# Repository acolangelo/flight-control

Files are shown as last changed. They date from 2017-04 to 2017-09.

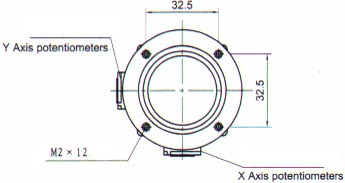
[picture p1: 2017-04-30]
3D/specs/3-axis-joystick-w-button-1.jpg

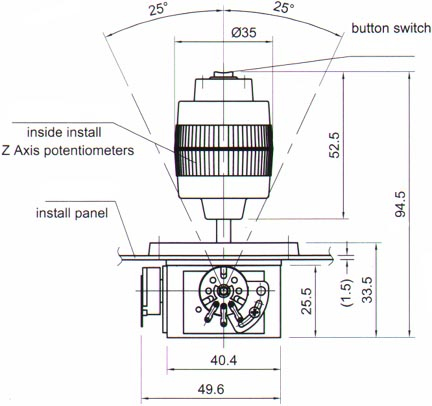
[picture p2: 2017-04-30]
3D/specs/3-axis-joystick-w-button-2.jpg

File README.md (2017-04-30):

# Flight Control

A few years ago, I decided to take my software skills into the physical world. I hacked some [Arduino](http://arduino.cc)-based projects together—circuits, some code, and plastic enclosures I bought from a supplier.

With the help of the [Big Cartel Employee Art Grant](https://www.bigcartel.com/team/#art-grants), I’m learning how to 3D print so I can design, prototype, and build my own enclosures for electronic projects.

First up, controllers for [Kerbal Space Program](https://kerbalspaceprogram.com) and [X-Plane](http://www.x-plane.com).

***

## Project Updates

**[Part 1: Humble Beginnings](https://acolangelo.com/blog/humble-beginnings)
<small>— MAY 2, 2016</small>**

Electronic Components and Test Parts

I’m up and running with my [Big Cartel Employee Art Grant](https://www.bigcartel.com/team/#art-grants) project. The 3D printer has arrived, and the first practice prints came out well.

***

**[Part 2: Component Tests](https://acolangelo.com/blog/component-tests)
<small>— OCTOBER 10, 2016</small>**

Joysticks and Throttle Component Test

I’ve been in the thick of my [Big Cartel Employee Art Grant](https://www.bigcartel.com/team/#art-grants) project for the past few months. I’ve been sourcing components, working on various mounts and enclosures, and designing the final product.

***

**[Part 3: Demo Flight](https://acolangelo.com/blog/demo-flight)
<small>— OCTOBER 27, 2016</small>**



After [putting together a component test unit](https://acolangelo.com/blog/component-tests), I hooked it up to a [Teensy++ 2.0](https://www.pjrc.com/store/teensypp.html)—the brains of the controller—and took it for a spin in X-Plane.

***

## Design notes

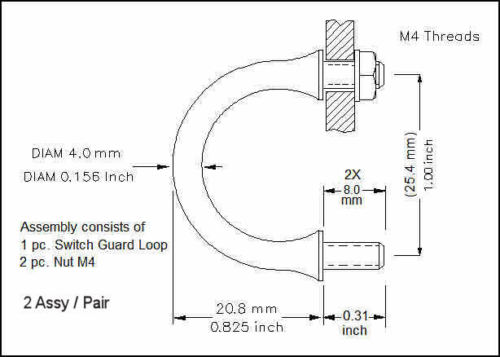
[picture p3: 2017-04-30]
3D/specs/switch-guard.jpg

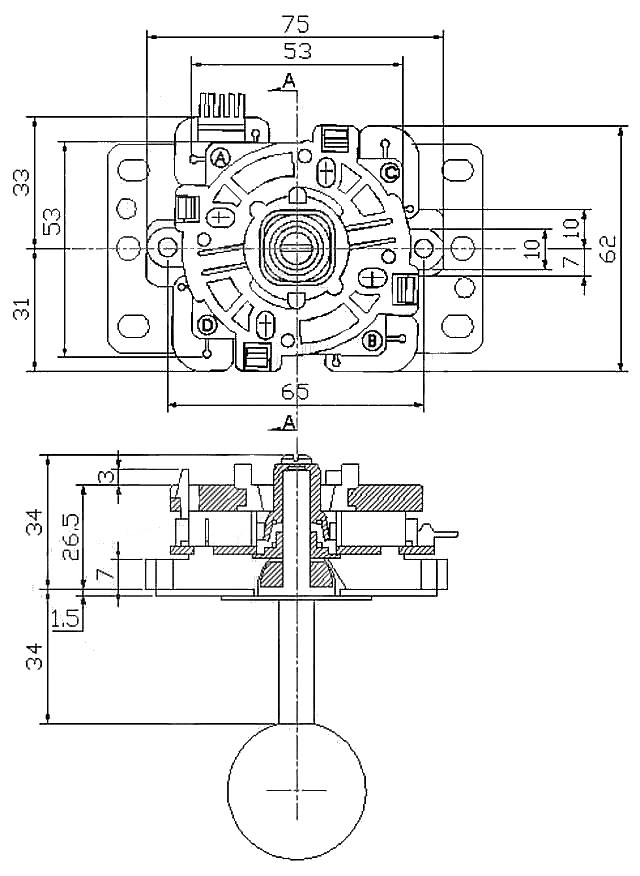
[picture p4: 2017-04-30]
3D/specs/joystick-zippy.jpg

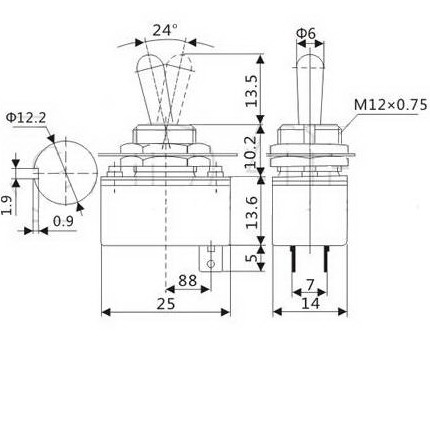
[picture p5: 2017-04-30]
3D/specs/toggle-switch.jpg

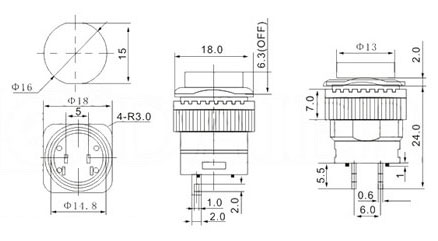
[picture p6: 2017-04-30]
3D/specs/button-led.jpg

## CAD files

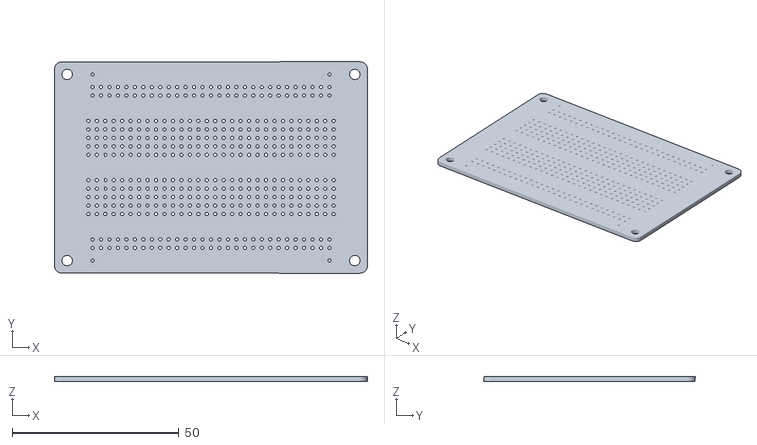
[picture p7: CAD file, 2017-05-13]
3D/objects/sparkfun-breadboard.stl
94.0 x 63.5 x 1.60

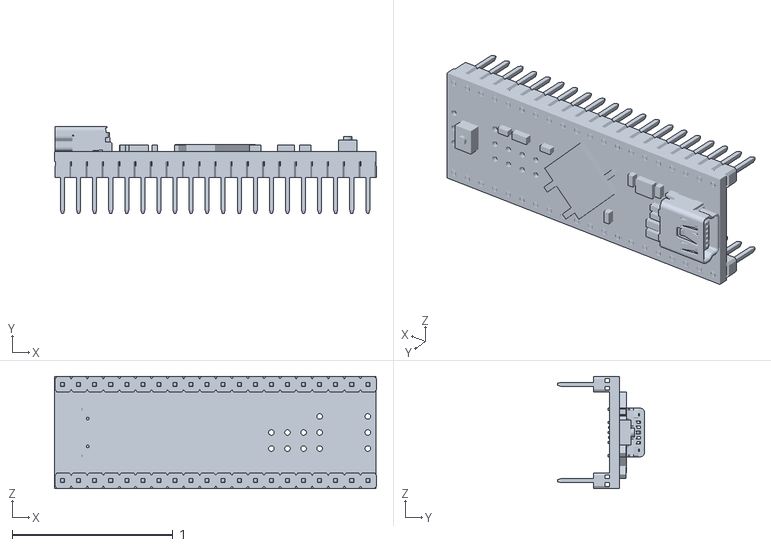
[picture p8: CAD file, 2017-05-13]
3D/objects/teensy-2-0.snapshot.4/Teensy++2.0.STL
2.00 x 0.541 x 0.7

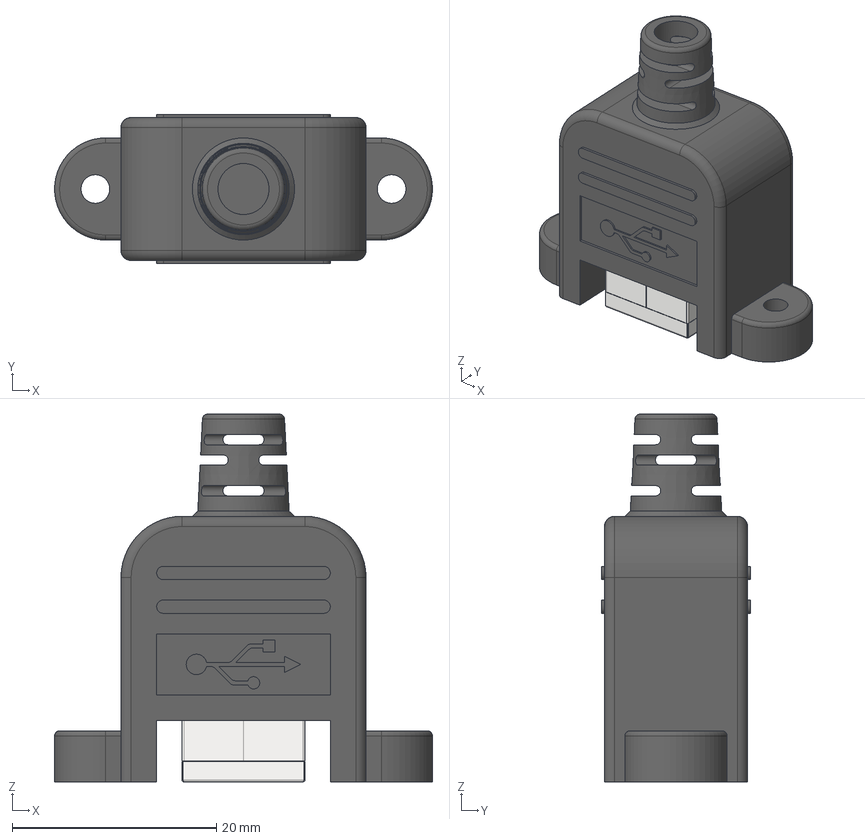
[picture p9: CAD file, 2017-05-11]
3D/objects/usb-type-b-panel-mount/USB_Type_B.stp
37.0 x 14.6 x 36.0 mm
USB_Type_B_Part1
USB_Type_B_Part3
USB_Type_B_Part2
USB_Type_B_Part4 x 4

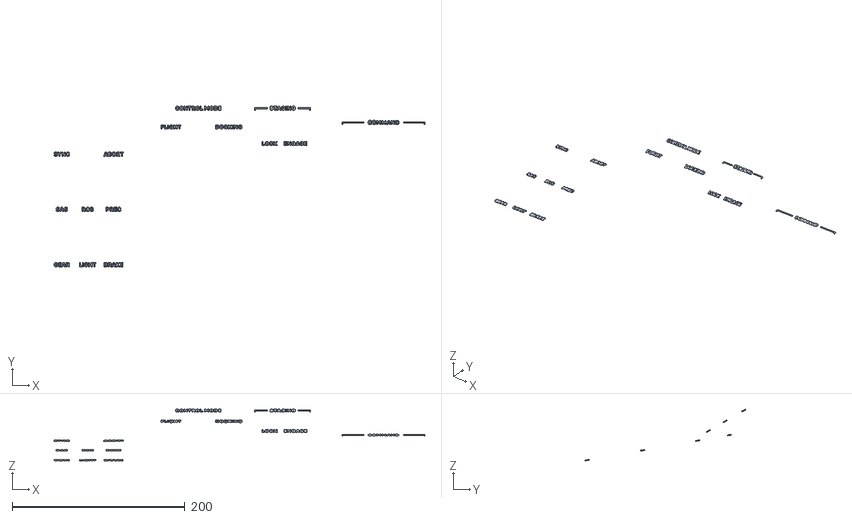
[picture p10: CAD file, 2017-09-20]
3D/print/letters.stl
429.9 x 186.3 x 60.0

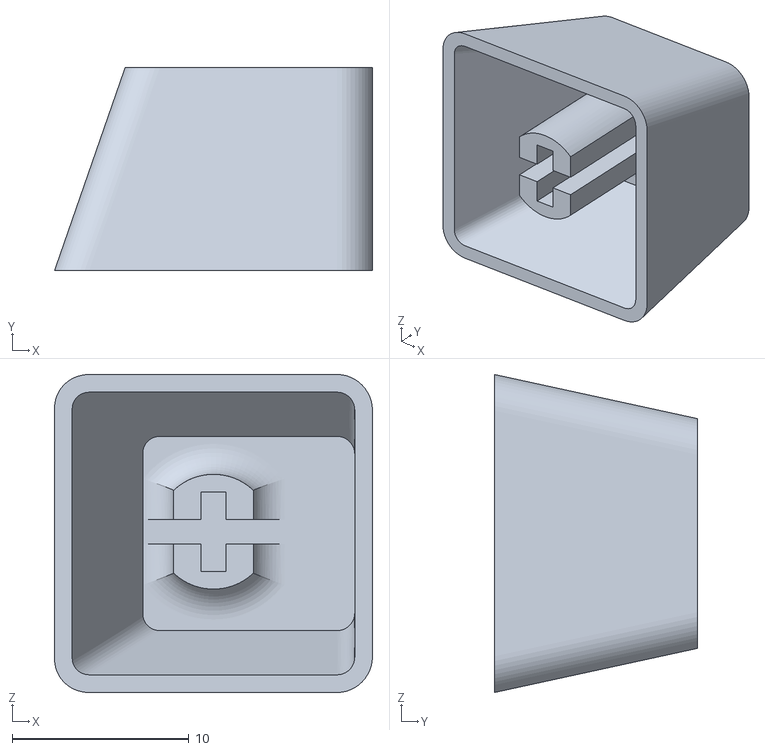
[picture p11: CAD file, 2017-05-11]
3D/objects/cherry-mx-key.stl
18.0 x 11.5 x 18.0

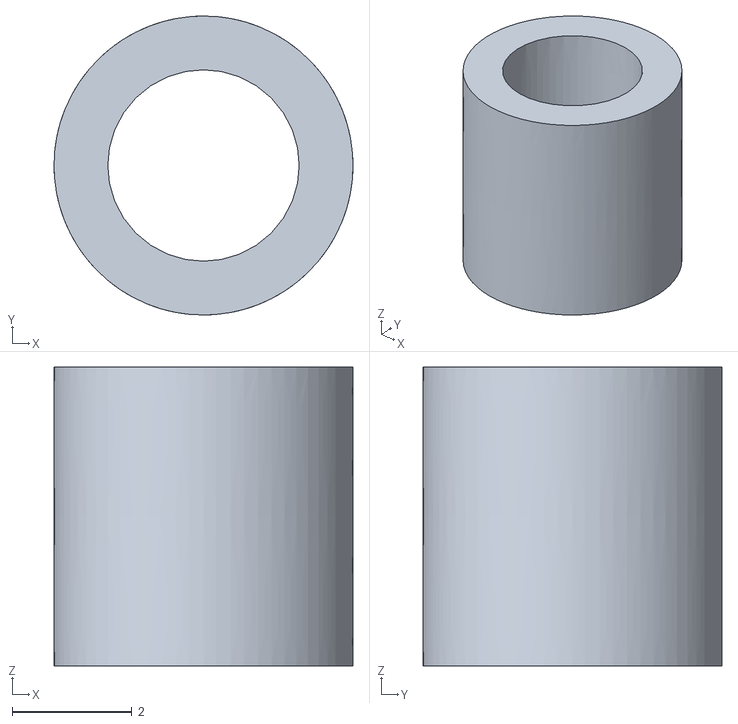
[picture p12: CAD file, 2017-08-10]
3D/print/breadboard-stub.stl
5.00 x 5.00 x 5.00

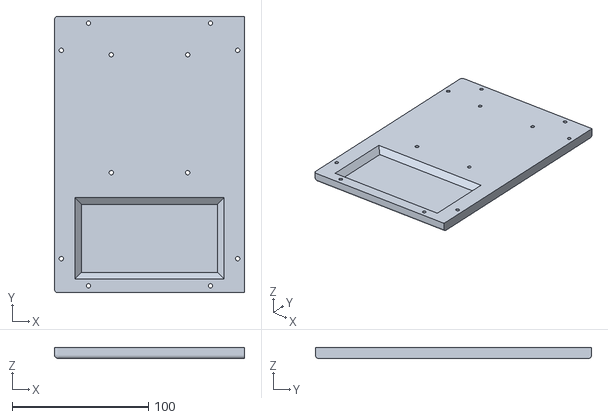
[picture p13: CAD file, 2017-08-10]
3D/print/left-bottom.stl
139.7 x 203.2 x 8.00

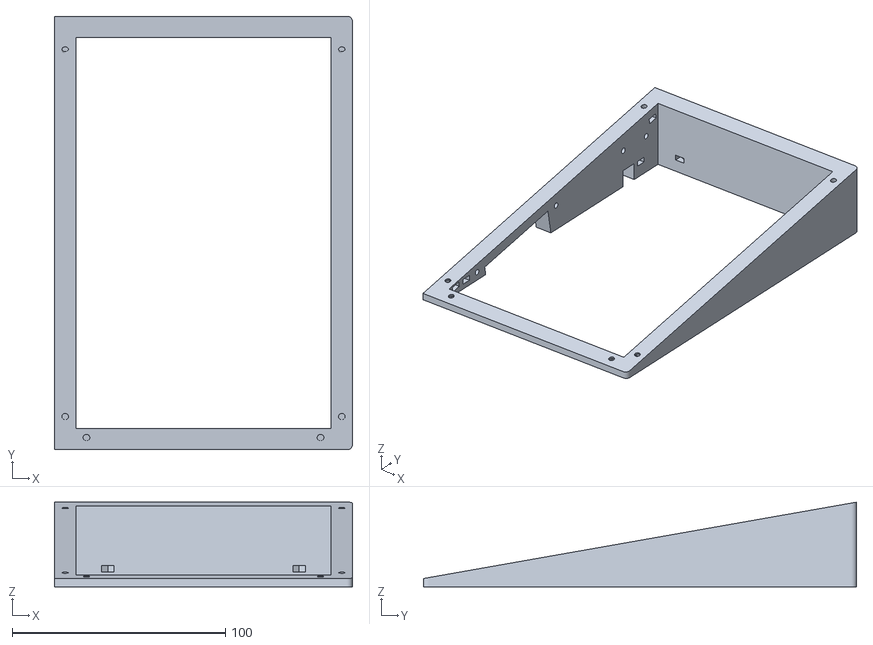
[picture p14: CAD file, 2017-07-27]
3D/print/right-sides.stl
139.7 x 203.2 x 39.7

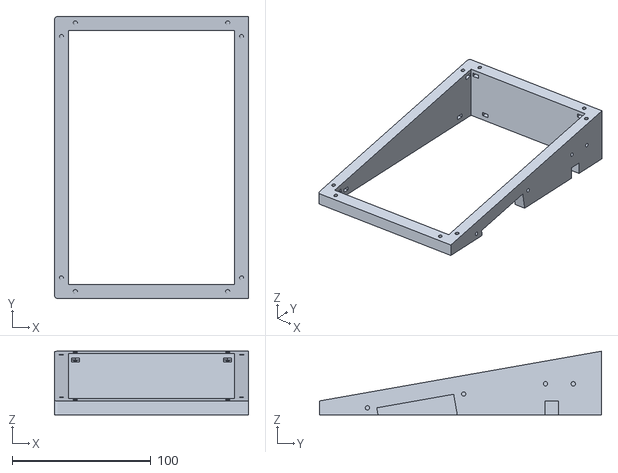
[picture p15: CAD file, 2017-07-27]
3D/print/left-sides.stl
139.7 x 203.2 x 45.8

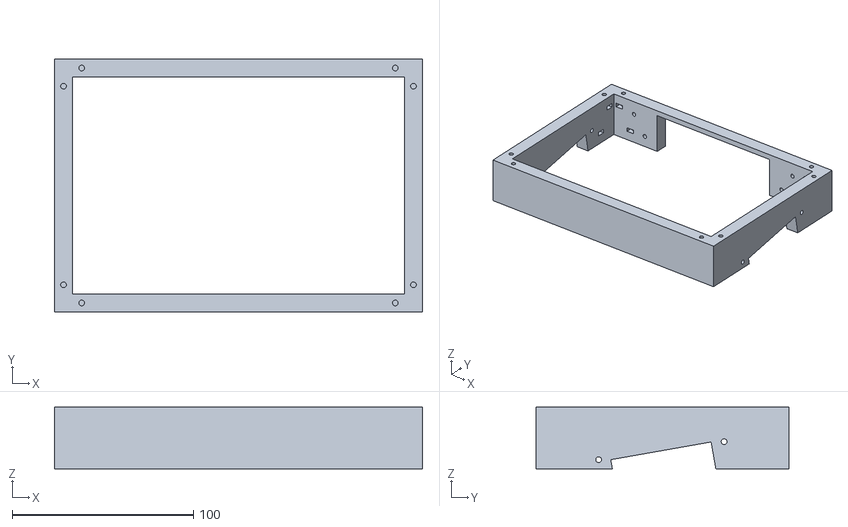
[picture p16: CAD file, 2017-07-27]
3D/print/middle-sides.stl
203.2 x 139.7 x 34.0

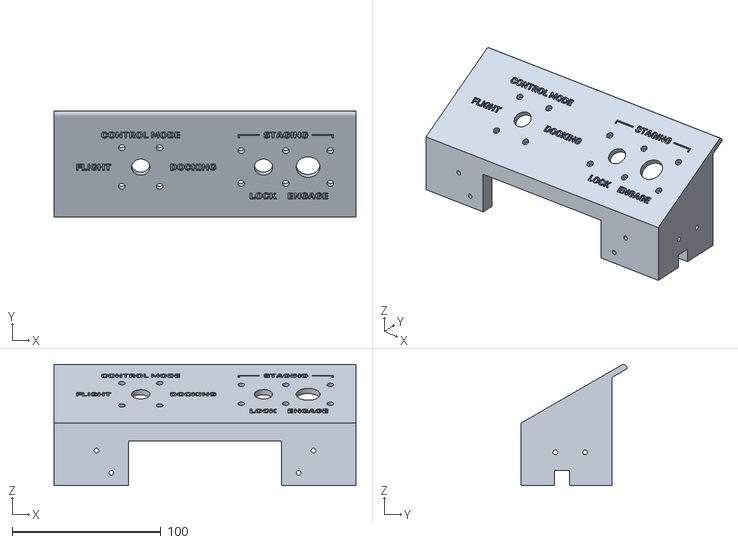
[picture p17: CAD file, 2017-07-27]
3D/print/back-top.stl
203.2 x 71.3 x 81.4

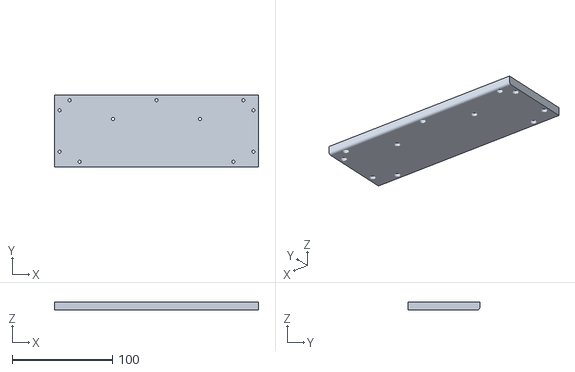
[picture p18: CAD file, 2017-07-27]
3D/print/back-bottom.stl
203.2 x 71.3 x 8.00

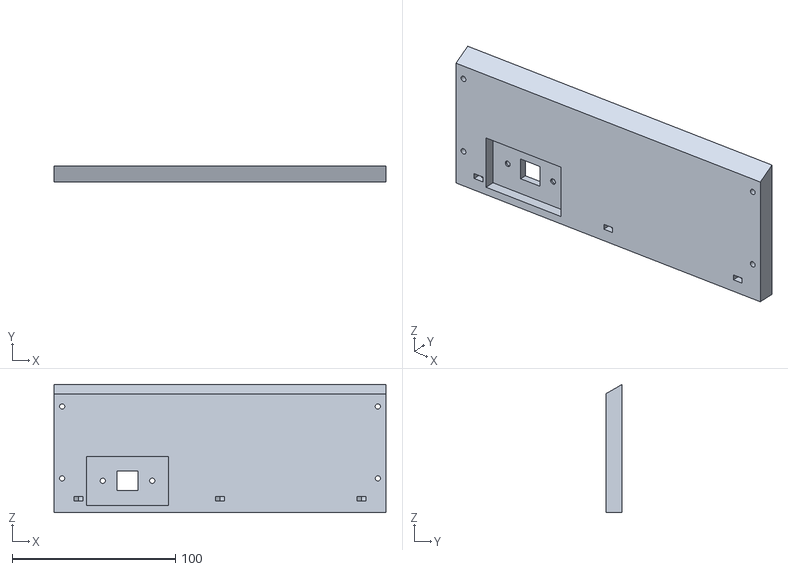
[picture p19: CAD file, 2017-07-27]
3D/print/back-panel.stl
203.2 x 10.0 x 78.5

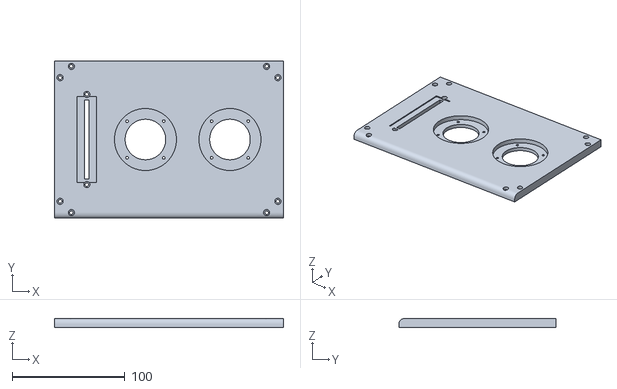
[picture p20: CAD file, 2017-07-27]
3D/print/middle-top.stl
203.2 x 139.7 x 8.00

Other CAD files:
3D/print/right-bottom.stl
3D/print/middle-bottom.stl
3D/print/right-top.stl
3D/designs/components.3dm
3D/exports/left-bottom.stl
3D/mounts/bolt-m3.3dm
3D/mounts/button-led.3dm
3D/mounts/cherry-mx-double.3dm
3D/mounts/cherry-mx.3dm
3D/mounts/joystick.3dm
3D/mounts/led.3dm
3D/mounts/m3-inset.3dm
3D/mounts/potentiometer.3dm
3D/mounts/switch-guard.3dm
3D/mounts/toggle-switch.3dm
3D/mounts/usb.3dm

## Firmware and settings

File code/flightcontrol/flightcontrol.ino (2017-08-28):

int buttonPins[]    = {0,   2,  3,  25, 17, 16, 15, 14, 13, 12, 11, 10, 9, 8};
int buttonButtons[] = {11,  14, 15, 16, 1,  2,  3,  4,  5,  6,  7,  8,  9, 10};

int togglePins[]    = {27,  1,  24, 23};
int toggleButtons[] = {13,  12, 17, 18};
int toggleStates[]  = {0,   0,  0,  0};

void setup() {  
  // Assign button pins to INPUT_PULLUP
  int i;
  for (i = 0; i < 14; i = i + 1) {
    pinMode(buttonPins[i], INPUT_PULLUP);
  }
  
  // Assign toggle pins to INPUT
  int j;
  for (j = 0; j < 4; j = j + 1) {
    // Control Mode needs resistor enabled.
    if (togglePins[j] == 27) {
      pinMode(togglePins[j], INPUT_PULLUP);
    } else {
      pinMode(togglePins[j], INPUT);
    }
  }
}

void loop() {
  
  // Read buttons
  int i;
  for (i = 0; i < 14; i = i + 1) {
    Joystick.button(buttonButtons[i], !digitalRead(buttonPins[i]));
  }
  
  // Read toggle switches
  int j;
  for (j = 0; j < 4; j = j + 1) {
    int currentState = digitalRead(togglePins[j]);
    if (toggleButtons[j] == 12) {
      if (currentState == toggleStates[j]) {
        continue;
      }
      // Staging Lock
      Keyboard.begin();
      Keyboard.press(KEY_LEFT_ALT);
      delay(1);
      Keyboard.press('l');
      delay(1);
      Keyboard.release('l');
      delay(1);
      Keyboard.release(KEY_LEFT_ALT);
      Keyboard.end();
    } else  if (toggleButtons[j] == 13) {
      // Control Mode
      if (currentState == toggleStates[j]) {
        continue;
      }
      Keyboard.begin();
      if (currentState == 0) {
        // Flight
        Keyboard.press('y');
        delay(1);
        Keyboard.release('y');
      } else if (currentState == 1) {
        // Docking
        Keyboard.press(KEY_DELETE);
        delay(1);
        Keyboard.release(KEY_DELETE);
      }
      Keyboard.end();
    } else {
//      if ¬
      //Joystick.button(toggleButtons[j], (currentState != toggleStates[j]));
      Joystick.button(toggleButtons[j], currentState);
    }
    toggleStates[j] = currentState;
  }
  
  // Right Joystick
  Joystick.X(analogRead(0));
  Joystick.Y(analogRead(1));
  Joystick.Z(analogRead(2));

  // Left Joystick
  Joystick.Zrotate(analogRead(3));
  Joystick.sliderRight(analogRead(4));
  Joystick.button(31, (analogRead(5) < 341));
  Joystick.button(32, (analogRead(5) > 680));

  // Throttle
  int throttleAmount = analogRead(6);
  if (throttleAmount < 40) {
    throttleAmount = 0;
  } else if (throttleAmount > 1010) {
    throttleAmount = 1023;
  }
  Joystick.sliderLeft(throttleAmount);
  
  delay(5);
}

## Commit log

2017-04-30 Added 3D.
    [bolt-m3.3dm, button-led.3dm, cherry-mx-double.3dm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]
2017-05-04 Arranged Command panel joints.
2017-05-05 Cut Command Panel joints.
2017-05-06 Positioned joints for main body and back panel.
2017-05-06 Positioned back panel bolts.
2017-05-06 Cut nuts and bolts in main body.
2017-05-06 Cut nuts and bolts in back panel.
2017-05-06 Cut pathways into body.
2017-05-11 Started adding bolts.
    [components.3dm]
2017-05-11 Added USB, toggle switches, guards.
    [USB_Type_B.stp, cherry-mx-key.stl]
2017-05-13 Added breadboard and Teensy to design.
    [Teensy++2.0.STL, sparkfun-breadboard.stl]
2017-07-27 Pre-side joint cuts.
    [left-bottom.stl, middle-top.stl, right-top.stl]
2017-07-27 Cut side fasteners.
2017-07-27 Exported prints.
    [back-bottom.stl, back-panel.stl, back-top.stl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]
2017-08-10 New bottom pieces to support breadboards.
    [breadboard-stub.stl, left-bottom.stl, right-bottom.stl]
2017-08-14 Completed middle panel circuits.
2017-08-28 Printed bottoms.
2017-09-20 Finished off letters.
    [letters.stl]
